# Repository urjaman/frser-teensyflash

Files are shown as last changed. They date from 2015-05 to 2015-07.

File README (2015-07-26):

Firmware for serprog on a Teensy 3.1,
supports my hardware (see hardware/)
with LPC,FWH and SPI.

You'll need to modify the Makefile
to point to your teensy toolchain,
assumed to be still inside
arduino 1.6.5.

It might be possible to still
compile under cygwin on windows,
but this was only tested on linux.

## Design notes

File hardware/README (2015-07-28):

There be the EAGLE files (.sch,.brd) here,
gerbers in the .zip.
And the board is also shared in oshpark:
https://oshpark.com/shared_projects/izukIxq8

It is actually a bit tricky to build,
but i managed it. Dont short the PLCC
pins to the pin holes and dont
push the pins through the holes,
just in the holes, because the PLCC
socket goes above them.

There's a more detailed assembly description at:
http://flashrom.org/Teensy_3.1_SPI_%2B_LPC/FWH_Flasher

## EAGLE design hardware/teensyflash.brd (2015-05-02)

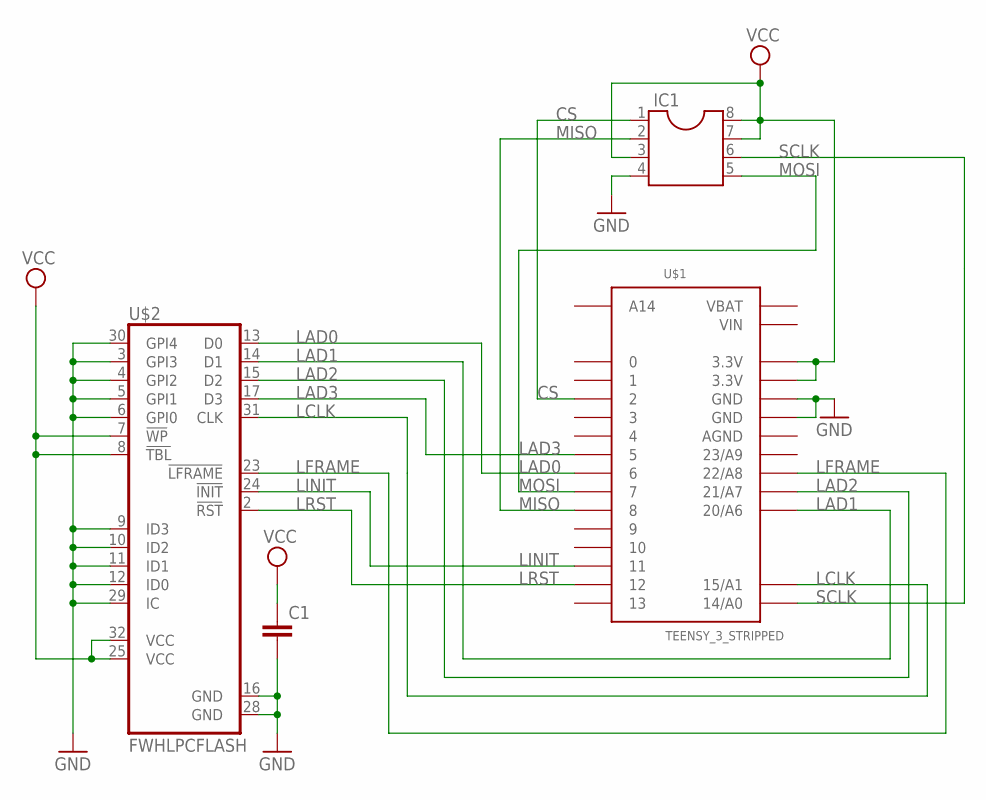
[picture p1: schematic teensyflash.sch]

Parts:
C1: C-EUC0805; C0805
IC1: DIL8; DIL08
U$1: TEENSY_3_STRIPPED
U$2: FWHLPCFLASH; PLCC32

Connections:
AGND: U$1.AGND
CS: IC1.1, U$1.2
GND: C1.2, IC1.4, U$1.GND, U$1.GND1 (GND), U$2.3 (GPI3), U$2.4 (GPI2), U$2.5 (GPI1), U$2.6 (GPI0), U$2.9 (ID3), U$2.10 (ID2), U$2.11 (ID1), U$2.12 (ID0), U$2.16 (GND), U$2.28 (GND), U$2.29 (IC), U$2.30 (GPI4)
LAD0: U$1.6, U$2.13 (D0)
LAD1: U$1.20/A6, U$2.14 (D1)
LAD2: U$1.21/A7, U$2.15 (D2)
LAD3: U$1.5, U$2.17 (D3)
LCLK: U$1.15/A1, U$2.31 (CLK)
LFRAME: U$1.22/A8, U$2.23 (!LFRAME)
LINIT: U$1.11, U$2.24 (!INIT)
LRST: U$1.12, U$2.2 (!RST)
MISO: IC1.2, U$1.8
MOSI: IC1.5, U$1.7
SCLK: IC1.6, U$1.14/A0
VBAT: U$1.VBAT
VCC: C1.1, IC1.3, IC1.7, IC1.8, U$1.3.3V, U$1.3.3V1 (3.3V), U$2.7 (!WP), U$2.8 (!TBL), U$2.25 (VCC), U$2.32 (VCC)
VIN: U$1.VIN

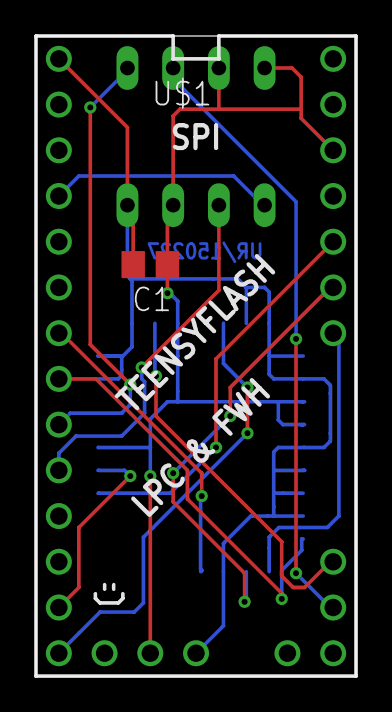
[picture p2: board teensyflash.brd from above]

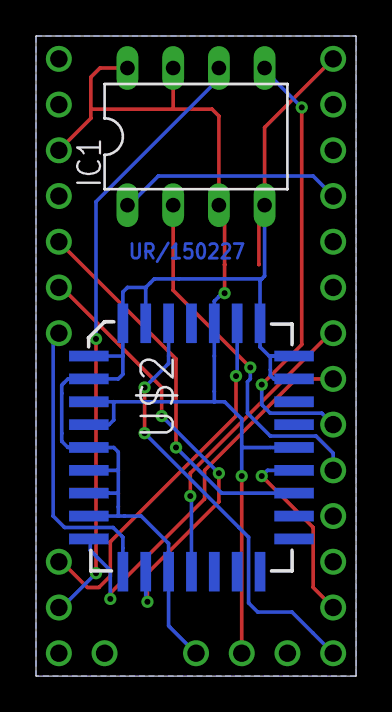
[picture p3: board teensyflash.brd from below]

Board: 2 copper layers, 17.8 x 35.6 mm, 4 parts (2 on the bottom side), 14 nets.

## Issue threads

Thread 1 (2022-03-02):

Hand Wiring Guide

xloem, 2022-03-02:
I actually breadboarded this, and often don't have an eagle schematic viewer installed.

Here's the wiring as text. If there are mistakes, I am sorry.

```
DIL8
Teensy 2 - DIL8 1 CS
Teensy 7 - DIL8 5 MOSI
Teensy 8 - DIL8 2 MISO
Teensy 14 - DIL8 6 SCLK
Teensy GND - DIL8 4
Teensy 3.3v - DIL8 3,7,8

PLCC
Teensy 5 - PLCC 17 D3
Teensy 6 - PLCC 13 D0
Teensy 11 - PLCC 24 INIT
Teensy 12 - PLCC 2 RST
Teensy 15 - PLCC 31 CLK
Teensy 20 - PLCC 14 AD1
Teensy 21 - PLCC 15 AD2
Teensy 22 - PLCC 23 LFRAME
Teensy GND - PLCC 3,4,5,6,9,10,11,12,16,28,29,30
Teensy 3.3v - PLCC 7,8,25,32
Capacitor goes between GND and 3.3v.
```
It would be good to know how big the capacitor should be, haven't found that yet.

xloem, 2022-03-14:
There's also a 3D-printed socket plug for prototyping at https://github.com/schlae/32plcc-plug

urjaman, 2023-10-18:
I guess 0.1µF (it might work without, just a local bypass for the flash chip),
i haven't touched this thing in 8 years and don't have EAGLE around either.

xloem, 2023-10-20:
Thanks for your design here, I had lots of fun porting coreboot for my board last year. Not using it right now, but it was a really great project.

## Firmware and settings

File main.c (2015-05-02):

/*
	This file is part of frser-teensyflash.
	Copyright (C) 2015 Urja Rannikko <urjaman@gmail.com>

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
	You should have received a copy of the GNU General Public License
	along with this program.  If not, see <http://www.gnu.org/licenses/>.
*/

#include "main.h"
#include "uart.h"
#include "frser.h"
//#include "usb_dev.h"
int main(void)
{
#if 1
	int i=0;
	PORTC_PCR5 = 0x0140;
	GPIOC_PSOR = _BV(5);
	GPIOC_PDDR |= _BV(5);
	for (i=0;i<3;i++) {
		GPIOC_PSOR = _BV(5);
		_delay_ms(100);
		GPIOC_PCOR = _BV(5);
		_delay_ms(100);
	}

#endif
	frser_main();
}

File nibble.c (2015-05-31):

/*
	This file was part of bbflash, now frser-teensyflash.
	Copyright (C) 2013, Hao Liu and Robert L. Thompson
	Copyright (C) 2013,2015 Urja Rannikko <urjaman@gmail.com>

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
	You should have received a copy of the GNU General Public License
	along with this program.  If not, see <http://www.gnu.org/licenses/>.
*/
#include "main.h"
#include "nibble.h"


#define nopx() asm volatile("nop")

#define delay() nopx()

/* CLK: PC0
 * FRAME: PC1
 * INIT: PC6
 * RST: PC7
 * LAD0: PD4
 * LAD1: PD5
 * LAD2: PD6
 * LAD3: PD7
 */

void nibble_set_dir(uint8_t dir) {
	if (!dir) {
		GPIOD_PDDR &= ~(0xF0);
	} else {
		GPIOD_PDDR |= 0xF0;
	}
}

uint8_t nibble_read(void) {
	return (GPIOD_PDIR>>4)&0x0F;
}

static void nibble_write_hi(uint8_t data) {
	GPIOD_PDOR = (GPIOD_PDOR & ~0xF0) | (data & 0xF0);
}

void nibble_write(uint8_t data) {
	GPIOD_PDOR = (GPIOD_PDOR & ~0xF0) | (data << 4);
}

#define clock_low() do { GPIOC_PCOR = _BV(0); } while(0)
#define clock_high() do { GPIOC_PSOR = _BV(0); } while(0)

void clock_cycle(void) {
	clock_low();
	delay();
	clock_high();
}


bool nibble_init(void) {
	int i;

	GPIOC_PCOR = _BV(6); // INIT=0

	clock_high();

	GPIOC_PSOR = _BV(1); // FRAME

	nibble_set_dir(OUTPUT);
	nibble_write(0);

	for (i = 0; i < 24; i++)
		clock_cycle();
	GPIOC_PSOR = _BV(6); // INIT=1
	for (i = 0; i < 42; i++)
		clock_cycle();

	return true;
}

void nibble_cleanup(void) {
	GPIOC_PDDR &= ~(_BV(7) | _BV(6) | _BV(1) | _BV(0));
	nibble_set_dir(INPUT);
}

void clocked_nibble_write(uint8_t value) {
	clock_low();
	nibble_write(value);
	clock_high();
}

void clocked_nibble_write_hi(uint8_t value) {
	clock_low();
	nibble_write_hi(value);
	clock_high();
}

uint8_t clocked_nibble_read(void) {
	clock_cycle();
	delay();
#if F_CPU > 48000000
	delay();
#endif
	return nibble_read();
}

void nibble_start(uint8_t start) {
	GPIOC_PSOR = _BV(1); // FRAME=1
	nibble_set_dir(OUTPUT);
	clock_high();
	GPIOC_PCOR = _BV(1); // FRAME=0
	nibble_write(start);
	clock_cycle();
	GPIOC_PSOR = _BV(1); // FRAME=1
}


void nibble_hw_init(void) {
	/* Port Init */
	PORTC_PCR0 = PORT_PCR_MUX(1) | PORT_PCR_DSE | PORT_PCR_PE | PORT_PCR_PS;
	PORTC_PCR1 = PORT_PCR_MUX(1) | PORT_PCR_DSE | PORT_PCR_PE | PORT_PCR_PS;
	PORTC_PCR6 = PORT_PCR_MUX(1) | PORT_PCR_DSE | PORT_PCR_PE | PORT_PCR_PS;
	PORTC_PCR7 = PORT_PCR_MUX(1) | PORT_PCR_DSE | PORT_PCR_PE | PORT_PCR_PS;

	PORTD_PCR4 = PORT_PCR_MUX(1) | PORT_PCR_DSE | PORT_PCR_PE | PORT_PCR_PS;
	PORTD_PCR5 = PORT_PCR_MUX(1) | PORT_PCR_DSE | PORT_PCR_PE | PORT_PCR_PS;
	PORTD_PCR6 = PORT_PCR_MUX(1) | PORT_PCR_DSE | PORT_PCR_PE | PORT_PCR_PS;
	PORTD_PCR7 = PORT_PCR_MUX(1) | PORT_PCR_DSE | PORT_PCR_PE | PORT_PCR_PS;

	GPIOC_PDDR |= _BV(7) | _BV(6) | _BV(1) | _BV(0);
	GPIOC_PSOR = _BV(7) | _BV(6) | _BV(1) | _BV(0);
	GPIOD_PDDR &= ~(0xF0);
	GPIOD_PSOR = 0xF0;

	/* Kick reset here so lpc/fwh.c doesnt need to know about how it is controlled. */
	GPIOC_PCOR = _BV(7); // RST=0
	_delay_us(1);
	GPIOC_PSOR = _BV(7); // RST=1
}

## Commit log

2015-03-04 Teensy 3.1 C Makefile base (in cygwin) ... ugh...
2015-04-26 spi: working, also configure the fake sizes of stuff to be saner
2015-05-02 Fix license headers etc
    [flash.c, main.c, nibble.c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]
2015-05-02 Implement RX buffering in uart.c
    To be on the safe side so there is always space somewhere
    (even during TX) for the amount of RX buffering we claim to have.
2015-05-02 Use libfrser provided hooks for busy led and uart tx
2015-05-02 make mybool use ints on the teensy, makes more sense on a 32bit mcu
2015-05-02 switch nibble delay back to a nop (it works)
    There is the mystery that the first time the LPC didnt work
    and then suddenly it did, i havent been able to figure out that.
2015-05-02 nibble: get rid of some unnecessary delays
    I left the one in clock_cycle ... but even that shouldnt be needed
    At 48Mhz the teensy should be capable of max 24Mhz thus always <33Mhz
    The delay in the readback might be needed.
2015-05-02 Add files for the hardware...
    [teensyflash.brd, teensyflash.sch]
2015-05-03 Make the pin ISRs use CLZ, it makes them smaller
    Note: this is untested, i have no pin ISRs in use...
2015-07-16 uart: Trying out sleeping a bit...
2015-07-16 default to overclocked 96Mhz
    seems to work fine and be used by lots of ppl, so ...
    drop to 48Mhz if you're scared, the bus speed is the same
    so shouldnt change SPI much - LPC needs CPU bit twiddling
    so this mostly for LPC.
    Warning: 72Mhz CPU makes for bad bus speed for SPI.
2015-07-16 We should have enough support for the pin state command, enable it.
    Now I think you should be able to ISP with the teensy 3.1.
    Somebody please test :)
2015-07-22 Update toolchain used by default to Teensyduino 1.24 / Arduino-1.6.5
    Also update usage of teensy_loader_cli to use the new soft reboot flag
2015-07-26 Update also the arduino version named in the README...
2015-07-28 It has arduino in the name, so i'd like to delete it asap, but for now... ;P

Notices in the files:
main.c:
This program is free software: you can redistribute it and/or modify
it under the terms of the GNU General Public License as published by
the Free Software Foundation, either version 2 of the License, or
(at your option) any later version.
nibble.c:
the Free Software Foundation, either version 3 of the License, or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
